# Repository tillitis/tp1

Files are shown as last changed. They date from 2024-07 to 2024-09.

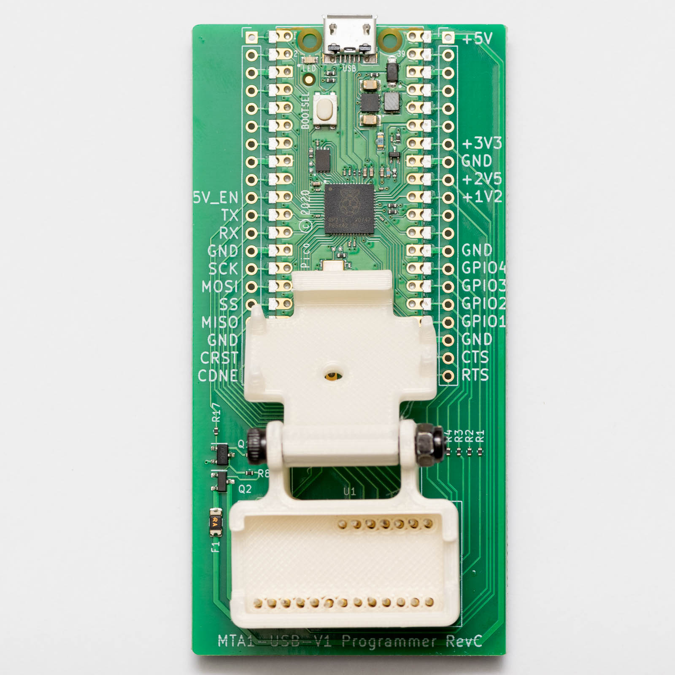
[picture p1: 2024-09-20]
prototypes/mta1-usb-v1-programmer/mta1-usb-v1-programmer.jpg

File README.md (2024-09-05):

# TKey Programmer 1

The TKey Programmer 1 (TP1) board is a tool used to program the FPGA
on a TKey. It consists of a RPI Pico and a jig where the TKey can be
placed.

## General usage

The board is interfaced using USB, and it will display itself as ID
`1209:8886 Generic TP-1`. The TKey is supposed to be placed in the jig
and one closes the lid carefully by pressing in the middle of the jig
(by the hole). To open the lid of the jig, it is easiest to simply
lift up on the lever.

The TP1 board supports two host computer tools to accommodate
programming of the TKey, either `iceprog` or `pynvcm`. See the chapter
in the [TKey Developer Handbook](https://dev.tillitis.se/tp1/) for a
more elaborate description on how to use it.

## Linux device permissions

To allow sudo-less programming, you need to be able to access the TKey
Programmer USB device. This is a raw USB device that is probably not
taken care of by your distribution.

You can install an udev rule that will assign the TP1 to the dialout
group. You will also need to add your user to the dialout group.

Create the following udev rule at `/etc/udev/rules.d`:

```
# TP-1 programmer
SUBSYSTEM=="usb", ENV{DEVTYPE}=="usb_device", ATTR{idVendor}=="1209", ATTR{idProduct}=="8886", MODE="0666", GROUP="dialout"
```

To reload the rules run:

```
sudo udevadm control --reload-rules
sudo usermod -aG dialout ${USER}
```

To apply the new group, log out and then log back in, or run the
command `newgrp dialout` in the terminal that you are working in.

You can check the device permissions to determine if the group was
successfully applied. First, use `lsusb` to find the location of the
programmer:

```
lsusb -d 1209:8886
Bus 001 Device 023: ID 1209:8886 Generic TP-1
```

Then, you can check the permissions by using the bus and device
numbers reported above like this:

```
ls -l /dev/bus/usb/001/023
crw-rw---- 1 root dialout 189, 22 Feb 16 14:58 /dev/bus/usb/001/023
```

Note that this pair of numbers is ephemeral and may change after every
device insertion.

## Firmware
The TP1 board runs a custom firmware developed by Blinkinlabs for
Tillitis. There is also a pre-built firmware binary at
`fw/bin/main.uf2`.

To update the firmware, either build the file `main.uf2` (more
instructions below) or get the pre-built file to your host computer.
Then do the following:

1. Disconnect the programming board from the host computer
2. Press and hold the "BOOTSEL" button on the RPi2040 sub-board on the
programming board
3. Reconnect the programming board to the host computer
4. Release the "BOOTSEL" button after connecting the programming board
to the host. The board should now appear to the host as a USB
connected storage device
5. Open the storage device and drop the firmware file `main.uf2` into
the storage device

The programmer will update its firmware with the file and restart
itself. After rebooting, the storage device will automatically be
disconnected.

### Building the firmware

The firmware requires the Raspberry Pi Pico SDK, the build script
assumes this is located either in your home home directory, or in
`/usr/local`. To clone to the home directory use

```
cd ~
git clone --branch 1.5.1 https://github.com/raspberrypi/pico-sdk.git
cd pico-sdk
git submodule update --init
```

then run the build script in the `fw` folder

```
./build.sh
```

Note that our container image (tkey-builder) places the pico-sdk
directory in `/usr/local`. For normal development, it is usually left
in the user's home directory.

See
[fw/README.md](https://github.com/tillitis/tp1/blob/main/fw//README.md)
for further instructions.

## KiCad

The PCB is built using KiCad version 7. Production files are built in
CI using KiBot, see the Makefile for exact version.

## License
### Hardware
Unless otherwise noted, this project is licensed under CERN Open
Hardware License Version 2 - Strongly Reciprocal, see full license
under [LICENSE.txt](/LICENSE.txt).
```
Copyright Tillitis AB 2022-2024.

This source describes Open Hardware and is licensed under the CERN-OHL-S v2.

You may redistribute and modify this source and make products using it under
the terms of the CERN-OHL-S v2 (https://ohwr.org/cern_ohl_s_v2.txt).

This source is distributed WITHOUT ANY EXPRESS OR IMPLIED WARRANTY,
INCLUDING OF MERCHANTABILITY, SATISFACTORY QUALITY AND FITNESS FOR A
PARTICULAR PURPOSE. Please see the CERN-OHL-S v2 for applicable conditions.

Source location: https://github.com/tillitis/tp1

As per CERN-OHL-S v2 section 4, should You produce hardware based on this
source, You must where practicable maintain the Source Location visible
on the external case of the product or its packaging, and in its
documentation, even after modification.
```

The [CERN-OHL-S user guide](/User-guide-CERN-OHL-S.txt) is included to
make it easier to follow the license, both as a Licensor or a Licensee.

### Firmware
The firmware running on the TP1 is licensed under MIT License, see the
full license [fw/LICENSE](fw/LICENSE).

Copyright (c) 2023 Tillitis AB.

### Raspberry Pi Pico
TKey Programmer board uses the Raspberry Pi Pico hardware, which are
provided by Raspberry Pi Ltd. For more details, visit the official
Raspberry Pi Pico documentation at
https://www.raspberrypi.com/licensing/

## Prototypes

Under `prototypes/`, an earlier version of the TP1 can be found, such as
the `mta1-usb-v1-programmer`.

## History
This repo was created by filtering out relevant commits and files from
the [tillitis/tillits-key1](https://github.com/tillitis/tillitis-key1)
repo.

The filtering removed all files and commits that weren't related to
the tp1 hardware. This was done using
[git-filter-repo](https://github.com/newren/git-filter-repo).

To replicate the results up until commit `f1158b1` in this repo,
checkout commit `354aecb` in `tillitis/tillitis-key1` and run
`git-filter-repo --path hw/boards/tp1 --path
hw/boards/mta1-usb-v1-programmer --path hw/boards/KiCad-RP Pico`

All filtered commits have intact date, author, and code. Some
unrelated files are removed from some commits, but the commit messages
are left unchanged. Commit sha, tags and signatures are new. For
complete history, please see tillitis/tillitis-key1 from commit
`354aecb` and earlier.

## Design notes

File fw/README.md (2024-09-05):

# Ice40 programmer

This firmware allows a Raspberry Pi Pico (or any RP2040) to work as a
programmer for the lattice ice40 parts.

It has been integrated into icestorm:
https://github.com/tillitis/icestorm/tree/interfaces

## Building the firmware

First, follow the details in the toolchain setup document to install
the Raspberry Pi Pico SDK. Then, the firmware can be built by running
the build script:

```
./build.sh
```

Once complete, the output binary is located in build/main.uf2

## Usage

First, program your RPi Pico using the included binary 'main.u2f'. To
do so, disconnect the pico from your computer, press down the
bootloader button, then plug the pico back in. The computer should
detect it as a memory device. Copy the main.u2f file into the root
directory of this memory device. This will program the Pico. Once
completed, the pico should restart and present itself as a USB RAW
device.

To use it with icestorm, the 'iceprog' utility will need to be built
from the above fork. Known issues:

* This version of iceprog is hard-coded to use the pico as a programmer; it
should have a command-line switch to choose the correct programmer
* SRAM programming mode (-S) is untested

TODO: Suggested wiring diagram

TODO: Permissions

## Version checking

The firmware version can be determined from the bcdDevice field in the
USB device descriptor. Known versions are:

| bcdDevice | Version | Description |
| --- | --- | --- |
| 0x0100 | 1.0 | Raw USB test version |
| 0x0200 | 2.0 | Release version |

The command set described in this document describes the version 2.0
format.

## Command set

Commands are sent to the device as [control
transfers](https://www-user.tu-chemnitz.de/~heha/hsn/chm/usb.chm/usb4.htm#Control).
The bRequest field is used to select the commmand, and any
configuration data associated with the command 

| Command | Direction | bRequest | wValue | wIndex | wLength |
| --- | ---  | --- | --- | --- | --- |
| Set pin directions | OUT | 0x30  | 0 | 0 | 8 |
| Set pullups/pulldowns | OUT | 0x31  | 0 | 0 | 12 |
| Set pin values | OUT | 0x32 | 0 | 0 | 8 |
| Get pin values | IN  | 0x32 | 0 | 0 | 4 |
| Configure SPI pins and clock speed | OUT | 0x40 | 0 | 0 | 5 |
| Perform a SPI transfer | OUT | 0x41 | 0 | 0 | 5+n |
| Read data from previous SPI transfer | IN  | 0x41 | 0 | 0 | n |
| Send SPI clocks | OUT | 0x42 | 0 | 0 | 0 |
| Read ADC inputs | IN  | 0x50 | 0 | 0 | 12 |
| Enter bootloader mode  | OUT | 0xE0 | 0 | 0 | 0 |

Additionally, the device supports an additional control transfer to
support driver assignment on Windows:

| Command | Direction | bRequest | wValue | wIndex | wLength | Description |
| ---  | ---  | --- |--- | --- |--- |--- |
| MS_DESCRIPTOR | IN | 0xF8 | 0 | 0 | x | Get a Microsoft OS compatible descriptor |

### Set pin directions

This command is used to set pin directions. The first field is a mask
of pins to update, and the second is a bitmap of the resulting states.
Any pin that has a bit set in the mask will be updated.

Data packet format:

| Offset | Length | Description |
| --- | --- | --- |
| 0x00 | 4 | uint32: Pin mask (1=set direction) |
| 0x04 | 4 | uint32: Pin direction (1=output, 0=input) |

### Set pin pullup/pulldown resistors

This command is used to set pin pullup/pulldown resistors. The first
field is a mask of pins to update, the second is the pull-up states,
and the third is the pull-down states. Any pin that has a bit set in
the mask will be updated.

Data packet format:

| Offset | Length | Description |
| --- | --- | --- |
| 0x00 | 4 | uint32: Pin mask (1=set direction) |
| 0x04 | 4 | uint32: Pin pullups (1=enable, 0=disable) |
| 0x08 | 4 | uint32: Pin pulldowns (1=enable, 0=disable) |

### Set pin values

This command is used to set the value of output pins. The first field
is a mask of pins to update, and the second is a bitmap of new output
values to apply. Any pin that has a bit set in the mask will be
updated.

Data packet format:

| Offset | Length | Description |
| --- | --- | --- |
| 0x00 | 4 | uint32: Pin mask (1=set direction) |
| 0x04 | 4 | uint32: Pin value (1=high, 0=low) |

### Read pin values

This command is used to read the value of all pins. Note that pins
which are confgured as outputs will report their current output
setting.

Data packet format:

| Offset | Length | Description |
| --- | --- | --- |
| 0x05 | 4 | uint32: Pin values (1=high, 0=low) |

### Set SPI configuration

This command is used to configure the SPI engine.

Data packet format:

| Offset | Length | Description |
| --- | --- | --- |
| 0x00 | 1 | GPIO pin number for SCK |
| 0x01 | 1 | GPIO pin number for CS |
| 0x02 | 1 | GPIO pin number for MOSI |
| 0x03 | 1 | GPIO pin number for MISO |
| 0x04 | 1 | SPI clock frequency, in MHz |

### Transfer SPI data

This command is used to send data over the pins currently configured
as the SPI interface. This command performs a full-duplex read/write
operation, and stores the read data in a buffer. To retrieve the data
read during this operation, issue a read command.

Data packet format:

| Offset | Length | Description |
| --- | --- | --- |
| 0x00 | 1 | 0: don't toggle CS; any other value: toggle CS |
| 0x01 | 4 | Bytes to transfer |
| 0x05 | 1-2040 | SPI data to transfer |

### Get data read during previous SPI transaction

This command is used to retrieve any data transferred during the
previous SPI transaction.

Data packet format:

| Offset | Length | Description |
| --- | --- | --- |
| 0x00 | 1-2040 | SPI data to transfer |

### SPI clock out

This command is used to toggle the SPI clock pin, but doesn't transfer
any data.

Data packet format:

| Offset | Length | Description |
| --- | --- | --- |
| 0x00 | 4 | Number of SPI bytes to clock |

### Read ADCs

This command is used to read the analog value of analog input pins
0-2. Each value is returned as a uint32_t value representing the
reading in microvolts.

Data packet format:

| Offset | Length | Description |
| --- | --- | --- |
| 0x01 | 4 | ADC channel 0 value, in microvolts |
| 0x05 | 4 | ADC channel 1 value, in microvolts |
| 0x09 | 4 | ADC channel 2 value, in microvolts |

### Bootloader

This command is used to put the device in bootloader mode. No data is
sent during this

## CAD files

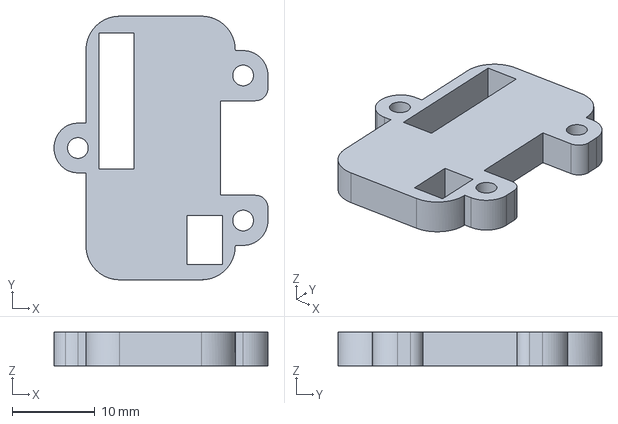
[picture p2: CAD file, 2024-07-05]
hw/clip_plastic/clip_base_spacer_30.stp
25.8 x 31.8 x 4.10 mm

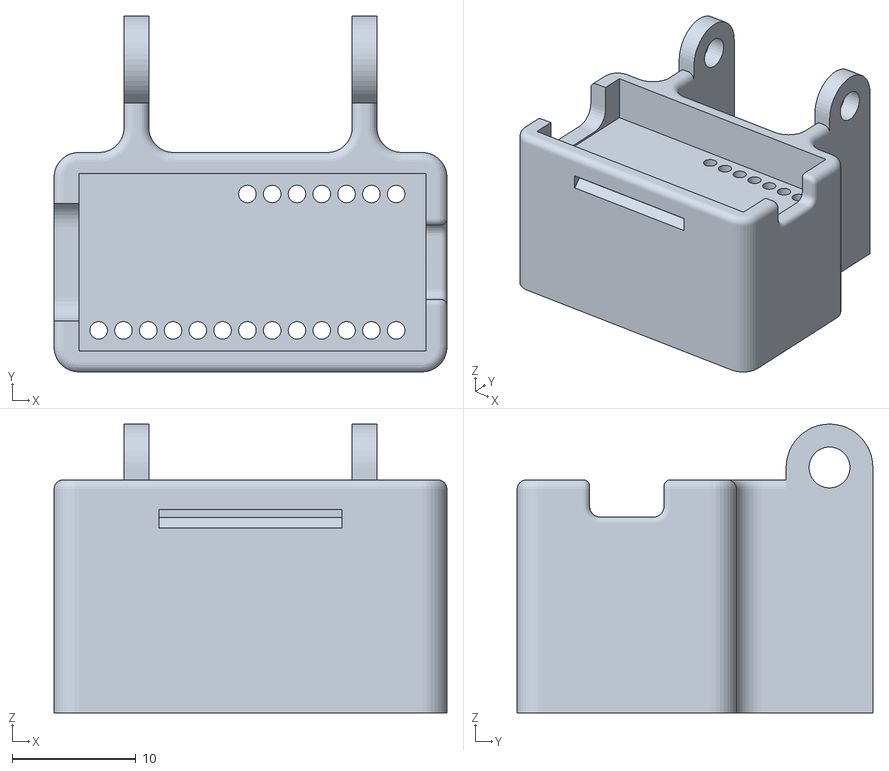
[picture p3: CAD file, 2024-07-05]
prototypes/mta1-usb-v1-programmer/clip_plastic/base-tk1.stl
31.7 x 28.7 x 23.3

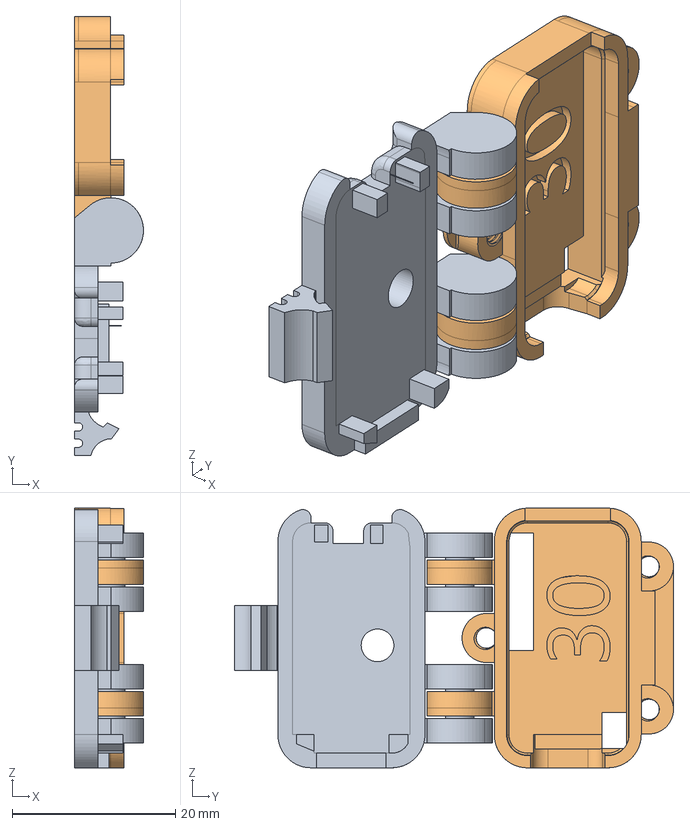
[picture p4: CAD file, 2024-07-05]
hw/clip_plastic/clip_base_30.stp
8.45 x 53.8 x 31.8 mm

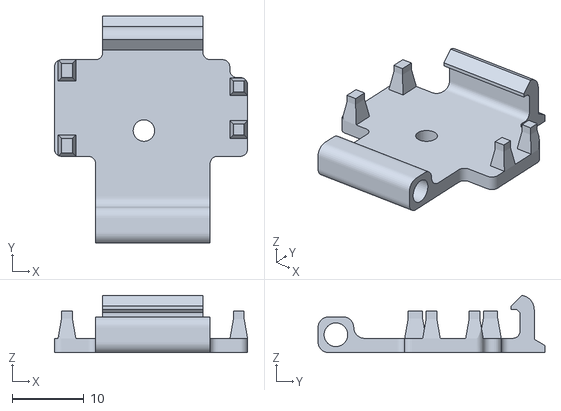
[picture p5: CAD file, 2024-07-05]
prototypes/mta1-usb-v1-programmer/clip_plastic/clip-tk1.stl
27.0 x 31.7 x 8.00

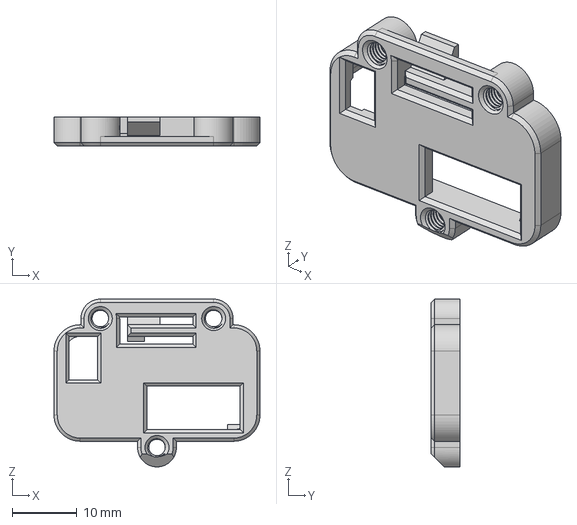
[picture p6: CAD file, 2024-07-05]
hw/clip_plastic/clip_base_15.step
31.8 x 4.40 x 25.9 mm

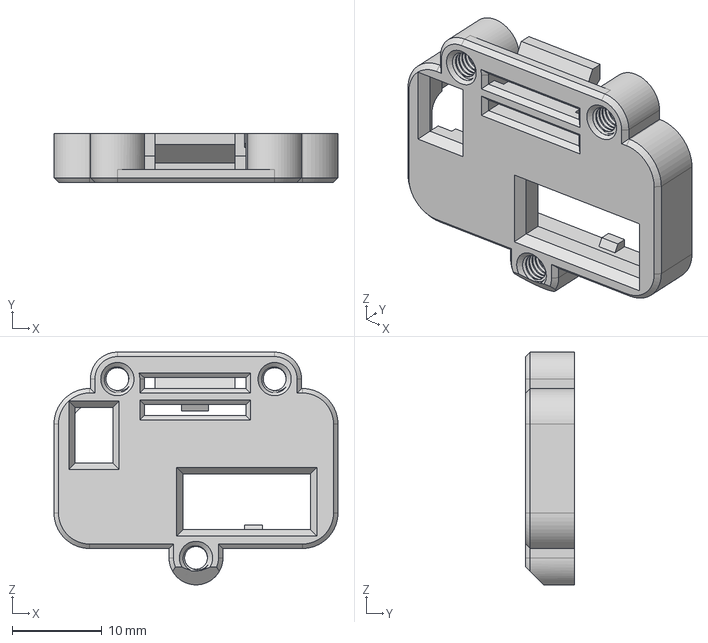
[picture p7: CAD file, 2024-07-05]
hw/clip_plastic/clip_base_24.step
31.6 x 5.40 x 25.9 mm

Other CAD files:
prototypes/mta1-usb-v1-programmer/clip_plastic/base-mta1.stl
prototypes/mta1-usb-v1-programmer/clip_plastic/clip-mta1.stl
hw/clip_plastic/clip_base_15.f3d
hw/clip_plastic/clip_base_24.f3d
hw/clip_plastic/clip_base_30.3mf

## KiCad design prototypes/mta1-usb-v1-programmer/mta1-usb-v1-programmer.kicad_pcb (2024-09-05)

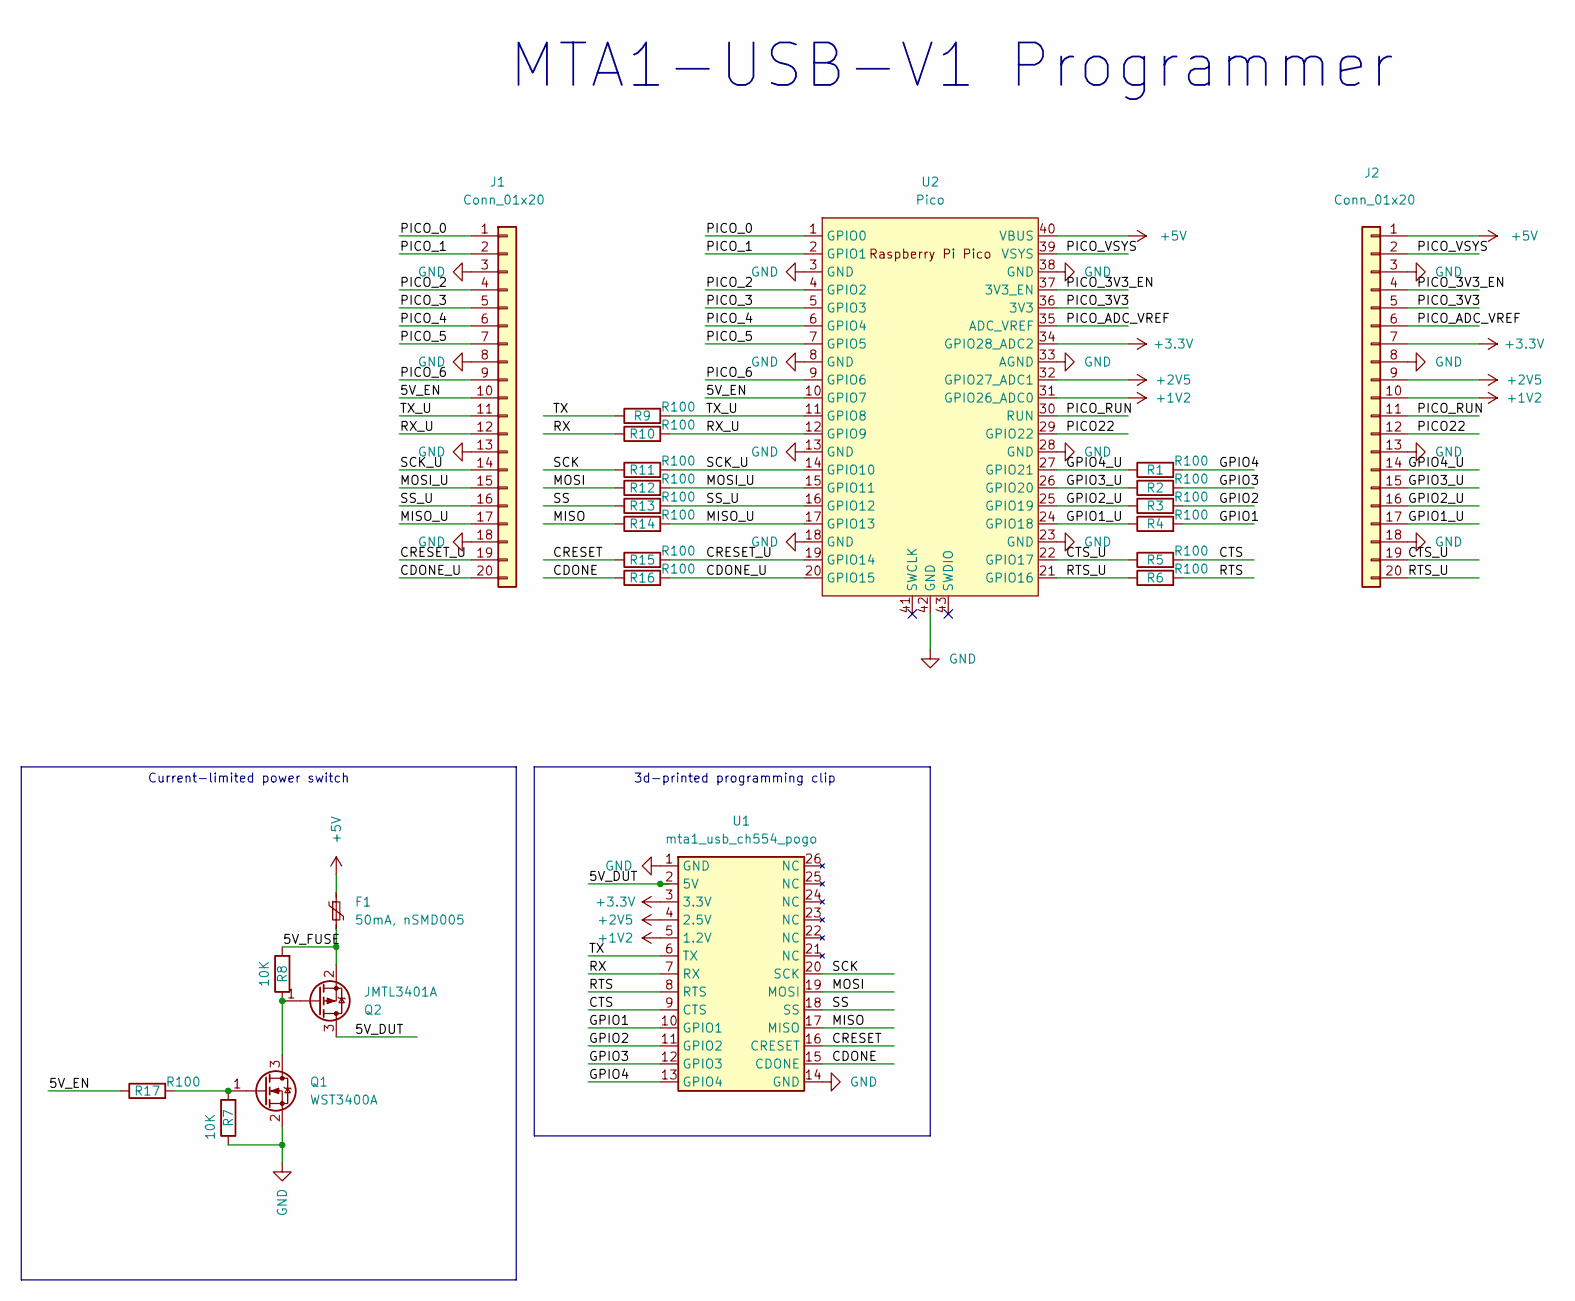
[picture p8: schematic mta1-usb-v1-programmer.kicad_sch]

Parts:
F1: 50mA, nSMD005; Fuse_1206_3216Metric; Manufacturer Part Number SMD1206P005TF
J1, J2: Conn_01x20; PinHeader_1x20_P2.54mm_Vertical
Q1: WST3400A; SOT-23; Manufacturer Part Number WST3400A
Q2: JMTL3401A; SOT-23; Manufacturer Part Number JMTL3401A
R1, R2, R3, R4, R5, R6, R9, R10, R11, R12, R13, R14, R15, R16, R17: R100; ERJ2G(0402)_L; Manufacturer Part Number AF0402FR-07100RL
R7, R8: 10K; ERJ2G(0402)_L; Manufacturer Part Number AT0402FRE0710KL
U1: mta1_usb_ch554_pogo
U2: Pico; RPi_Pico_SMD_TH; Manufacturer Part Number SC0915

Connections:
+1V2: J2.10, U1.5 (1.2V), U2.31 (GPIO26_ADC0)
+2V5: J2.9, U1.4 (2.5V), U2.32 (GPIO27_ADC1)
+3V3: J2.7, U1.3 (3.3V), U2.34 (GPIO28_ADC2)
+5V: F1.1, J2.1, U2.40 (VBUS)
/5V_DUT: Q2.3 (D), U1.2 (5V)
/5V_EN: J1.10, R17.1, U2.10 (GPIO7)
/5V_FUSE: F1.2, Q2.2 (S), R8.2
/CDONE: R16.1, U1.15 (CDONE)
/CDONE_U: J1.20, R16.2, U2.20 (GPIO15)
/CRESET: R15.1, U1.16 (CRESET)
/CRESET_U: J1.19, R15.2, U2.19 (GPIO14)
/CTS: R5.2, U1.9 (CTS)
/CTS_U: J2.19, R5.1, U2.22 (GPIO17)
/GPIO1: R4.2, U1.10 (GPIO1)
/GPIO1_U: J2.17, R4.1, U2.24 (GPIO18)
/GPIO2: R3.2, U1.11 (GPIO2)
/GPIO2_U: J2.16, R3.1, U2.25 (GPIO19)
/GPIO3: R2.2, U1.12 (GPIO3)
/GPIO3_U: J2.15, R2.1, U2.26 (GPIO20)
/GPIO4: R1.2, U1.13 (GPIO4)
/GPIO4_U: J2.14, R1.1, U2.27 (GPIO21)
/MISO: R14.1, U1.17 (MISO)
/MISO_U: J1.17, R14.2, U2.17 (GPIO13)
/MOSI: R12.1, U1.19 (MOSI)
/MOSI_U: J1.15, R12.2, U2.15 (GPIO11)
/PICO22: J2.12, U2.29 (GPIO22)
/PICO_0: J1.1, U2.1 (GPIO0)
/PICO_1: J1.2, U2.2 (GPIO1)
/PICO_2: J1.4, U2.4 (GPIO2)
/PICO_3: J1.5, U2.5 (GPIO3)
/PICO_3V3: J2.5, U2.36 (3V3)
/PICO_3V3_EN: J2.4, U2.37 (3V3_EN)
/PICO_4: J1.6, U2.6 (GPIO4)
/PICO_5: J1.7, U2.7 (GPIO5)
/PICO_6: J1.9, U2.9 (GPIO6)
/PICO_ADC_VREF: J2.6, U2.35 (ADC_VREF)
/PICO_RUN: J2.11, U2.30 (RUN)
/PICO_VSYS: J2.2, U2.39 (VSYS)
/RTS: R6.2, U1.8 (RTS)
/RTS_U: J2.20, R6.1, U2.21 (GPIO16)
/RX: R10.1, U1.7 (RX)
/RX_U: J1.12, R10.2, U2.12 (GPIO9)
/SCK: R11.1, U1.20 (SCK)
/SCK_U: J1.14, R11.2, U2.14 (GPIO10)
/SS: R13.1, U1.18 (SS)
/SS_U: J1.16, R13.2, U2.16 (GPIO12)
/TX: R9.1, U1.6 (TX)
/TX_U: J1.11, R9.2, U2.11 (GPIO8)
GND: J1.3, J1.8, J1.13, J1.18, J2.3, J2.8, J2.13, J2.18, Q1.2 (S), R7.1, U1.1 (GND), U1.14 (GND), U2.3 (GND), U2.8 (GND), U2.13 (GND), U2.18 (GND), U2.23 (GND), U2.28 (GND), U2.33 (AGND), U2.38 (GND), U2.42 (GND)
unnamed: Q1.1 (G), R7.2, R17.2
unnamed: Q1.3 (D), Q2.1 (G), R8.1

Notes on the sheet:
Current-limited power switch
MTA1-USB-V1 Programmer
3d-printed programming clip

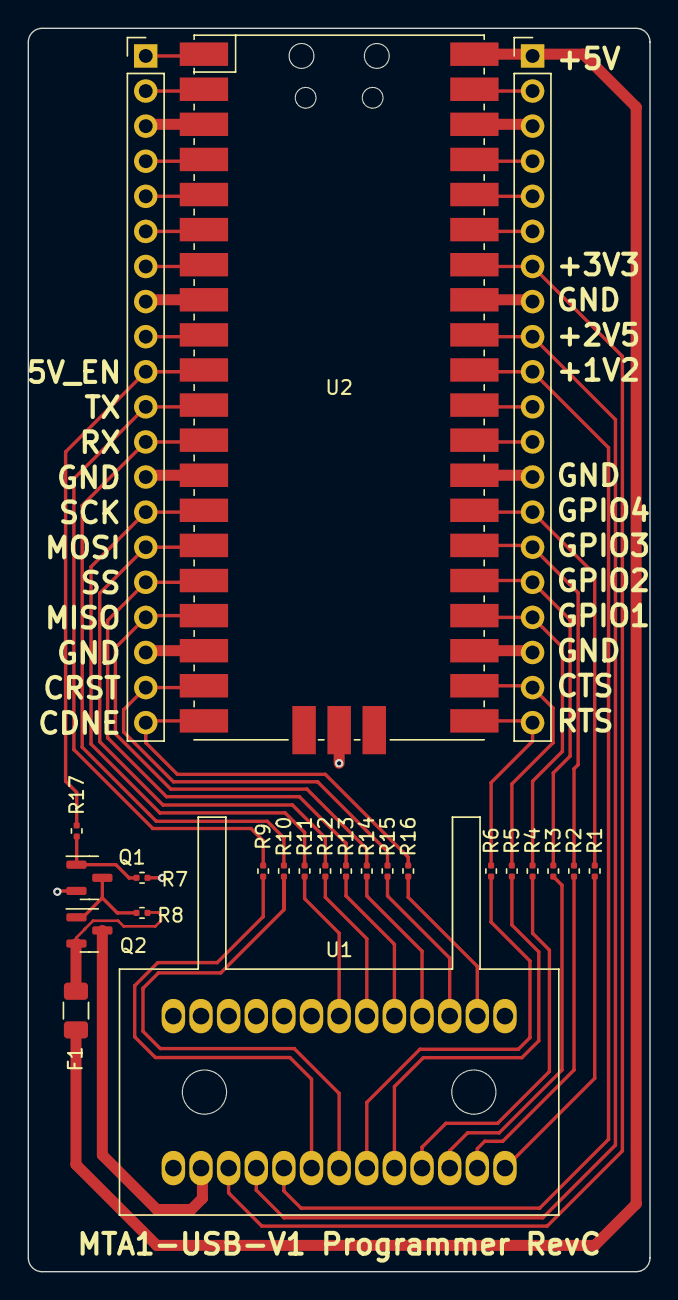
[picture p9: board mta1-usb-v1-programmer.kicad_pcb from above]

Board: 2 copper layers, 45.0 x 90.0 mm, 24 parts (0 on the bottom side), 51 nets.

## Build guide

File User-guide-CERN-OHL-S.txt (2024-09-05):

CERN Open Hardware Licence Version 2 - Strongly Reciprocal

                           User Guide

                         September 2, 2020
                         Guide version: 1.0

1 Introduction

This document contains guidelines on how to apply the CERN-OHL-S v2 to a given
hardware design, and on the use of hardware designs licensed under CERN-OHL-S
v2. This means we will be talking to you sometimes as a licensor, and other
times as a licensee.
As a licensor, there are many ways in which you can make it clear to your
licensees that you are sharing your designs under the licence. These guidelines
are only to be taken as advice, illustrating some ways in which we think this
can be done efficiently.
To help you distinguish between requirements imposed by the licence (mostly as a
licensee) and our suggestions to you (mostly as a licensor), we will use the
word 'rule' for the former and the word 'suggestion' for the latter. Any
perceived contradiction between these guidelines and the licence text should of
course be resolved in favour of the licence text.

2 How to apply CERN-OHL-S v2 to a hardware design

2.1 Pre-requisite

Authorship/ownership of the design must be clear and undisputed. Only the legal
owner of the rights in the hardware design may decide under what conditions to
make it available. Generally, if ownership is vested in more than one
person/entity, there must be an agreement among the owners (or a chain of
compatible licences from each of them) to release the hardware design as open
hardware, and under the CERN-OHL-S v2 in particular.

2.2 Your sources

Nowadays, most designers who intend to share their work do so by hosting their
design files (sources) in a publicly-accessible repository using version control
systems such as git. The sites hosting these repositories usually provide users
with the convenience of downloading a whole repository as a compressed (e.g.
zip) file. Using these platforms is a very effective way of working: it makes it
easier for you to receive feedback, shows your users the complete history of the
project and allows them to easily start using it and contributing improvements.

2.2.1 Suggestion: try to host your design in a publicly-accessible repository
      using version control. If that is not possible, compress your whole
      directory structure into one file and publish that file, so users get your
      whole project in one go.

If your goal is to share, it makes sense to provide enough information to users
about the contents of the design package they download, and to make it easy for
them to browse that information. For example, if you have designed your hardware
using proprietary tools, people who download the design files may not have
access to the tools you used. Sometimes you can also provide exported versions
of those files which, although not as useful for modification as the originals,
will make life easier for people who want to understand your designs. For
example, PCB schematics and layout can be exported as pdf files, and 3D
mechanical designs can be exported to the STEP format.

2.2.2 Suggestion: include in your design sources versions of the files exported
      to formats everybody can read. It would be helpful to specify the tools
      you used, and, if they are publicly available under free and open source
      licences, provide information about where the recipient can find them.

It can also be good to let people know that you are following this guide, so
they see why you are doing things in this or that way.

2.2.3 Suggestion: include a copy of this user guide, in pdf or plain text
      format, in your sources.

Of course, although not strictly necessary, you should also include a copy of
the licence text (CERN-OHL-S v2 in this case) in pdf or plain text form. Your
design files will anyway be identified as licensed under that licence, with a
URL pointing to the licence text, but it does not hurt to include the licence
text in the source package for the convenience of the user and to make it very
visible that the whole design is open source.

2.2.4 Suggestion: include a copy of the CERN-OHL-S v2 licence text, in pdf or
      plain text format, in your sources, and failing that, provide a link to
      the licence at https://ohwr.org/cern_ohl_s_v2.txt.

One of the requirements for licensees who make modifications to the design and
publish those modifications is to make them explicit in a dedicated text file.
As a licensor, you can make this obligation more easy for licensees to see and
bear in mind by including a placeholder file called CHANGES.txt in your sources.

2.2.5 Suggestion: include an empty CHANGES.txt file in your sources. You may
      write a few lines in the beginning of the file stating that anyone
      modifying the design should provide brief information about the
      modifications, including the date they were made, and stating that
      information about the design should be added but never removed from that
      file. It could also state that, according to section 3.3.b of the licence,
      licensees should provide a brief entry with a date and the nature of the
      modification for each design change. For example '26 April 2020: AC/DC
      power converter circuit removed as AC input no longer necessary'.

Now, as you have seen, as the initial licensor, relatively few rules apply to
you. We are going to assume that it is your intent to license your design under
CERN-OHL-S v2 though, and in that sense the minimal requirements are going to be
described as 'rules' below. Some files can easily include a header or a text box
with copyright and licensing information which will be easily visible to whoever
opens them. For file types which do not easily grant that possibility, consider
using a separate text file taking as its name the name of the original file with
'.license' appended to it. So if you have e.g. a file called
`my_3d_design.FCStd', you can add another file in the same directory called
`my_3d_design.FCStd.license' which is a text file containing copyright and
licensing information. If the number of files in your project is large and the
'.license' method is deemed too cumbersome, you can centralise all your
licensing information in a single text file following the Debian DEP5
specification. Both the '.license' and the DEP5 methods are suggested in the
REUSE guidelines. See https://reuse.software/for details.

2.2.6 Rule: include for each source file, either embedded in the file itself or
      in a separate text file which refers to it:
       (a) a copyright notice reflecting actual ownership;
       (b) a notice that the hardware design source is licensed under the CERN-
           OHL-S v2, possibly with a link to https://ohwr.org/cern_ohl_s_v2.txt:
             i."Licensed under CERN-OHL-S v2 or any later version" or
            ii."Licensed under CERN-OHL-S v2";
       (c) a disclaimer of warranties;
       (d) a Source Location if you wish to specify one;
       (e) optionally, a Notice specifying that you wish the Source Location to
           remain visible on the Product (or its packaging, or in its
           documentation) even after modifications.

Here is an example for a hypothetical designer called Sam Smith hosting a
design called Gizmo at https://example_url:

 ------------------------------------------------------------------------------
| Copyright Sam Smith 2020.                                                    |
|                                                                              |
| This source describes Open Hardware and is licensed under the CERN-OHL-S v2. |
|                                                                              |
| You may redistribute and modify this source and make products using it under |
| the terms of the CERN-OHL-S v2 (https://ohwr.org/cern_ohl_s_v2.txt).         |
|                                                                              |
| This source is distributed WITHOUT ANY EXPRESS OR IMPLIED WARRANTY,          |
| INCLUDING OF MERCHANTABILITY, SATISFACTORY QUALITY AND FITNESS FOR A         |
| PARTICULAR PURPOSE. Please see the CERN-OHL-S v2 for applicable conditions.  |
|                                                                              |
| Source location: https://example_url                                         |
|                                                                              |
| As per CERN-OHL-S v2 section 4, should You produce hardware based on this    |
| source, You must where practicable maintain the Source Location visible      |
| on the external case of the Gizmo or other products you make using this      |
| source.                                                                      |
 ------------------------------------------------------------------------------

The first three lines in the example above, containing copyright and licence
type, can be substituted by a valid SPDX header, like this:

SPDX-FileCopyrightText: 2020 Sam Smith <sam@example.com>
SPDX-License-Identifier: CERN-OHL-S-2.0

or, in case the 'or any later version' option is preferred:

SPDX-FileCopyrightText: 2020 Sam Smith <sam@example.com>
SPDX-License-Identifier: CERN-OHL-S-2.0+

2.2.7 Suggestion: use standard SPDX headers whenever possible so that your
      choice of licence is easy to understand by humans and computers alike.

Why would you license your design under 'CERN-OHL-S v2 or any later version'?
Imagine we discovered a shortcoming of the licence which made us write a new
version, let's say version 3.0, to fix it. Let us further imagine that we
decided to make v3 incompatible with v2 (this actually happened with the GPL).
If you licensed your design under 'v2 only' that means it could not be combined
with new designs licensed under v3. If, on the other hand, you license your
design under 'v2 or any later version', you give future licensees the option of
interpreting the design as licensed under the hypothetical v3, and there would
be no compatibility issues. This is quite an important decision to take when you
use a reciprocal licence, so we thought we'd mention it in this guide. You have
to make your own judgment as to whether you believe that CERN can be trusted to
ensure that future versions of the CERN-OHL will be similar in spirit and effect
to this version.

2.2.8 Suggestion: give some thought to the 'or any later version' option before
      publishing your design under CERN-OHL-S v2.

We are going to assume that you, as a licensor, want people who receive a
product based on your design to know that it is Open Hardware and where they can
find the design files for that product, hence:

2.2.9 Rule: include in a part of the Source corresponding to a visible part of
      the Product (e.g. silkscreen or top copper for a printed circuit board):
        (a) the licence notice: "Licensed under CERN-OHL-S v2";
        (b) the Source Location.

2.2.10 Suggestion: You can optionally include a copyright notice to be printed
       on the Product (remember you must keep intact any Notices in the source,
       though). If you do, and your design includes part of other designs, you
       should at least acknowledge the work is not all your own by using e.g.
       Copyright Sam Smith and others. In any case, do not include the CERN
       logo.

2.3 A Note on Components

If your design is modular, consider licensing each of the components you have
designed separately, and then having an overarching design, also licensed under
an appropriate variant of CERN-OHL which contains each of the sub-components as
an Available Component. This will make life easier for licensees who only want
to make use of one component of your design.

3 How to deal with hardware designs licensed under CERN-OHL-S v2

Generally speaking, you must comply with the requirements applying to a
particular design detailed in the accompanying licence. If you receive hardware
designs licensed under the CERN-OHL-S v2, the requirements are to:

3.1 Rule: keep intact all the copyright, acknowledgement and trademark notices
    and Source Location notices that are on the hardware design sources.

3.2 Rule: keep intact the references to the CERN-OHL-S v2.

3.3 Rule: keep intact the disclaimer of warranties.

3.1 Design modifications and publication

If you modify a hardware design licensed by someone else under CERN-OHL-S v2,
and you want to publish your modified design, or you need to publish it e.g. as
a result of the obligations attached to the production and distribution of
products, you must:

3.1.1 Rule: keep intact all the notices referred to above, although you may
      remove notices that are no longer relevant to your design (for example, if
      the design you are using contains a power supply and a processor board,
      and you are only using the processor board in your own design, you can
      remove the notices relating to the power supply, so long as you are sure
      they only relate to the power supply).

3.1.2 Rule: include notices stating that you have modified the hardware de-
      signs, giving a date and information about the modifications you have made
      (e.g. in a CHANGES.txt file).

3.1.3 Rule: add the appropriate copyright notice and Source Location to the
      modifications that were made.

3.1.4 Rule: license the modifications under the 'CERN-OHL-S v2' (or 'CERN- OHL-S
      v2 or any later version' if permitted by the original licensor, and all
      other components of the design allow you to license with the 'or any later
      version' option).

3.1.5 Rule: if your design is a modification of someone else's design, or
      incorporates parts of another's design, and in each case the other's
      design is released under CERN-OHL, CERN-OHL-W or CERN-OHL-S you must (if
      your tools allow this) include in your design sources versions of the
      files exported to formats everybody can read using tools available under a
      free or open source software licence. By CERN-OHL we mean any of the
      earlier versions of the licence, prior to v2.

3.2 Hardware production and distribution

If, as a licensee, you want to produce hardware based on a design licensed under
CERN-OHL-S v2 and/or distribute that hardware, you need to:

3.2.1 Rule: either provide each recipient with a copy of the Complete Source or
      ensure that each recipient is notified of the Source Location of the
      Complete Source.

By Complete Source, we mean all files needed to make the hardware. Please see
the licence text for details. You also need to respect, if applicable, the
will expressed by the licensor to have a clear visual indication of the Source
Location on the hardware:

3.2.2 Rule: if specified in a Notice by the licensor, the Product must visibly
      and securely display the Source Location on it or its packaging or
      documentation in the manner specified in that Notice.

4 Asking for help

If there is something unclear in this guide, or you have any question on how to
apply the licence, the best place to ask is the CERN OHL forum at
https://forums.ohwr.org/c/cernohl. You may also find useful information in the
FAQs at https://www.ohwr.org/project/cernohl/wikis/faq.

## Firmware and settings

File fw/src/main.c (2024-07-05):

/*
 * The MIT License (MIT)
 *
 * Copyright (c) 2019 Ha Thach (tinyusb.org)
 *
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
 */

#include <stdlib.h>
#include <stdio.h>
#include <string.h>
#include <hardware/gpio.h>
#include <hardware/adc.h>
#include "pico/bootrom.h"
#include "bsp/board.h"
#include "tusb.h"
#include "pio_spi.h"

//--------------------------------------------------------------------+
// MACRO CONSTANT TYPEDEF PROTYPES
//--------------------------------------------------------------------+

/* Blink pattern
 * - 250 ms  : device not mounted
 * - 1000 ms : device mounted
 * - 2500 ms : device is suspended
 */
enum
{
    BLINK_NOT_MOUNTED = 250,
    BLINK_MOUNTED = 1000,
    BLINK_SUSPENDED = 2500,
};


static bool do_reset = false;

static uint32_t blink_interval_ms = BLINK_NOT_MOUNTED;

#define BULK_TRANSFER_MAX_SIZE 2048 // Maximum control transfer data length
#define SPI_MAX_TRANSFER_SIZE (BULK_TRANSFER_MAX_SIZE-8)


pio_spi_inst_t spi = {
    .pio = pio0,
    .sm = 0,
    .cs_pin = 0
};

uint pio_offset;

void led_blinking_task(void);

void pins_init();

/*------------- MAIN -------------*/
int main(void)
{
    board_init();
    tusb_init();

    pio_offset = pio_add_program(spi.pio, &spi_cpha0_program);

    pins_init();

    adc_init();

    while (1)
    {
        tud_task(); // tinyusb device task
        led_blinking_task();

        if(do_reset) {
            reset_usb_boot(0,0);
        }
    }

    return 0;
}

//--------------------------------------------------------------------+
// Device callbacks
//--------------------------------------------------------------------+

// Invoked when device is mounted
void tud_mount_cb(void)
{
    blink_interval_ms = BLINK_MOUNTED;
}

// Invoked when device is unmounted
void tud_umount_cb(void)
{
    blink_interval_ms = BLINK_NOT_MOUNTED;
}

// Invoked when usb bus is suspended
// remote_wakeup_en : if host allow us  to perform remote wakeup
// Within 7ms, device must draw an average of current less than 2.5 mA from bus
void tud_suspend_cb(bool remote_wakeup_en)
{
    (void)remote_wakeup_en;
    blink_interval_ms = BLINK_SUSPENDED;
}

// Invoked when usb bus is resumed
void tud_resume_cb(void)
{
    blink_interval_ms = BLINK_MOUNTED;
}

#define PIN_COUNT 32 // PIN_MASK is 32 bits, so that's the max number of pins available
#define PIN_MASK (0b00011100011111111111111111111111)
// #define PIN_MASK ((1<<PIN_COUNT) - 1)
// #define PIN_MASK (0xFFFFFFFF)

void pins_init()
{
    gpio_init_mask(PIN_MASK);
}

//! @brief Set the pull-up state for the gpios specified in the pinmask
void set_pulls_masked(
    const uint32_t mask,
    const uint32_t ups,
    const uint32_t downs)
{
    for (int gpio = 0; gpio < PIN_COUNT; gpio++)
    {
        if (!(PIN_MASK & (1 << gpio)))
            continue;

        if (mask & (1 << gpio))
        {
            gpio_set_pulls(gpio, ups & (1 << gpio), downs & (1 << gpio));
        }
    }
}

uint32_t get_directions_all() {
    uint32_t pin_directions = 0;

    for (int gpio = 0; gpio < PIN_COUNT; gpio++)
    {
        pin_directions |= (gpio_get_dir(gpio)) << gpio;
    }

    return pin_directions;
}

void spi_xfer(bool handle_cs,
                 const uint32_t byte_count,
                 uint8_t const *buf_out,
                 uint8_t *buf_in)
{
    if(byte_count > SPI_MAX_TRANSFER_SIZE)
        return;

    if((buf_in == NULL) && (buf_out == NULL))
        return;

    if(buf_in != NULL)
        memset(buf_in, 0, SPI_MAX_TRANSFER_SIZE);

    if(handle_cs)
        gpio_put(spi.cs_pin, false);

    if(buf_in == NULL) { // Write transaction
        pio_spi_write8_blocking(&spi, buf_out, byte_count);
    }
    else if(buf_out == NULL) { // Read transaction
        pio_spi_read8_blocking(&spi, buf_in, byte_count);
    }
    else { // Full-duplex transaction
        pio_spi_write8_read8_blocking(&spi, buf_out, buf_in, byte_count);
    }

    if(handle_cs)
        gpio_put(spi.cs_pin, true);
}

uint32_t adc_sample_input(uint8_t input)
{
    if (input > 3)
    {
        return 0;
    }

    // Configure the GPIO
    adc_gpio_init(input + 26);

    adc_select_input(input);

    // 12-bit conversion, assume max value == ADC_VREF == 3.3 V
    const uint32_t conversion_factor = 3300000 / (1 << 12); // microvolts per sample
    uint16_t result = adc_read();

    return result * conversion_factor;
}

uint32_t read_uint32(uint8_t const *buffer)
{
    const uint32_t val =
        (*(buffer + 0) << 24) + (*(buffer + 1) << 16) + (*(buffer + 2) << 8) + (*(buffer + 3) << 0);
    return val;
}

void write_uint32(uint32_t val, uint8_t *buffer)
{
    buffer[0] = ((val >> 24) & 0xFF);
    buffer[1] = ((val >> 16) & 0xFF);
    buffer[2] = ((val >> 8) & 0xFF);
    buffer[3] = ((val >> 0) & 0xFF);
}


typedef enum
{
    COMMAND_PIN_DIRECTION = 0x30,           // Configurure GPIO pin directions
    COMMAND_PULLUPS = 0x31,                 // Configure GPIO pullups
    COMMAND_PIN_VALUES = 0x32,              // Set GPIO output values
    COMMAND_SPI_CONFIGURE = 0x40,           // Configure SPI pins
    COMMAND_SPI_XFER = 0x41,                // SPI transaction with CS pin
    COMMAND_SPI_CLKOUT = 0x42,              // Just toggle the clock
    COMMAND_ADC_READ = 0x50,                // Read ADC inputs
    COMMAND_BOOTLOADER = 0xE0,              // Jump to bootloader mode

    COMMAND_MS_OS_DESCRIPTOR = 0xF8
} command_t;

static const uint8_t microsoft_os_compatible_id_desc[] = {
	40, 0, 0, 0, // total length, 16 header + 24 function * 1
	0, 1, // Version 1
	4, 0, // Extended compatibility ID descriptor index
	1, // Number of function sections
	0, 0, 0, 0, 0, 0, 0, // Reserved
	0, // Interface number
	1, // Reserved
	'W','I','N','U','S','B',0,0, // compatibleID
	0,0,0,0,0,0,0,0,             // subCompatibleID
	0,0,0,0,0,0 // Reserved
};

uint8_t out_buffer[BULK_TRANSFER_MAX_SIZE]; // Host->Device data
uint8_t in_buffer[BULK_TRANSFER_MAX_SIZE];  // Holds Device->Host data

uint8_t spi_in_buffer[SPI_MAX_TRANSFER_SIZE];   // Holds read values from last SPI transfer

// Invoked when a control transfer occurred on an interface of this class
// Driver response accordingly to the request and the transfer stage (setup/data/ack)
// return false to stall control endpoint (e.g unsupported request)
bool tud_vendor_control_xfer_cb(uint8_t rhport, uint8_t stage, tusb_control_request_t const *request)
{
    // Only handle vendor requests
    if (request->bmRequestType_bit.type != TUSB_REQ_TYPE_VENDOR)
        return false;

    if ((stage == CONTROL_STAGE_SETUP) && (request->bmRequestType_bit.direction == 1))
    { // Device to host (IN)
        memset(in_buffer, 0, sizeof(in_buffer));

        switch (request->bRequest)
        {
	    case COMMAND_MS_OS_DESCRIPTOR:
		// TODO: Check index
            memcpy(in_buffer,
			    microsoft_os_compatible_id_desc,
			    sizeof(microsoft_os_compatible_id_desc)
			    );
            return tud_control_xfer(rhport,
			    request,
			    (void *)(uintptr_t)in_buffer,
			    sizeof(microsoft_os_compatible_id_desc)
			    );
            break;

        case COMMAND_PIN_VALUES:
            write_uint32(gpio_get_all() & PIN_MASK, &in_buffer[0]);
            return tud_control_xfer(rhport, request, (void *)(uintptr_t)in_buffer, 4);
            break;

        case COMMAND_ADC_READ:
            write_uint32(adc_sample_input(0), &in_buffer[0]);
            write_uint32(adc_sample_input(1), &in_buffer[4]);
            write_uint32(adc_sample_input(2), &in_buffer[8]);
            return tud_control_xfer(rhport, request, (void *)(uintptr_t)in_buffer, (3*4));
            break;

        case COMMAND_SPI_XFER:
            return tud_control_xfer(rhport, request, (void *)(uintptr_t)spi_in_buffer, sizeof(spi_in_buffer));
            break;

        default:
            break;
        }
    }
    else if ((stage == CONTROL_STAGE_SETUP) && (request->bmRequestType_bit.direction == 0))
    { // Host to device (OUT): Set up request to handle DATA stage
        switch (request->bRequest)
        {
        case COMMAND_PIN_DIRECTION:
        case COMMAND_PULLUPS:
        case COMMAND_PIN_VALUES:
        case COMMAND_SPI_CONFIGURE:
        case COMMAND_SPI_XFER:
        case COMMAND_SPI_CLKOUT:
            return tud_control_xfer(rhport, request, (void *)(uintptr_t)out_buffer, sizeof(out_buffer));
            break;

	case COMMAND_BOOTLOADER:
            do_reset = true;
            return true;
            break;

        default:
            break;
        }
    }
    else if ((stage == CONTROL_STAGE_ACK) && (request->bmRequestType_bit.direction == 0))
    { // Host to device (OUT): Handle data
        switch (request->bRequest)
        {
        case COMMAND_PIN_DIRECTION:
            gpio_set_dir_masked(
                read_uint32(&out_buffer[0]) & PIN_MASK,
                read_uint32(&out_buffer[4]) & PIN_MASK);
            return true;
            break;

        case COMMAND_PULLUPS: // set pullups/pulldowns
            set_pulls_masked(
                read_uint32(&out_buffer[0]) & PIN_MASK,
                read_uint32(&out_buffer[4]) & PIN_MASK,
                read_uint32(&out_buffer[8]) & PIN_MASK);
            return true;
            break;
            
        case COMMAND_PIN_VALUES: // set pin values
            gpio_put_masked(
                read_uint32(&out_buffer[0]) & PIN_MASK,
                read_uint32(&out_buffer[4]) & PIN_MASK);
            return true;
            break;

        case COMMAND_SPI_CONFIGURE:
            if(out_buffer[4] == 0)
                return false;

            pio_spi_init(spi.pio, spi.sm, pio_offset,
                         8,       // 8 bits per SPI frame
                         (31.25f/out_buffer[4]),  // 1 MHz @ 125 clk_sys
                         false,   // CPHA = 0
                         false,   // CPOL = 0
                         out_buffer[0], //sck
                         out_buffer[2], // mosi
                         out_buffer[3]  // miso
            );
            spi.cs_pin = out_buffer[1]; // cs

            return true;
            break;

        case COMMAND_SPI_XFER:
            spi_xfer(
                out_buffer[0],  // CS
                read_uint32(&out_buffer[1]),    // byte length
                &out_buffer[5], // data
                spi_in_buffer
                );
            
            return true;
            break;

        case COMMAND_SPI_CLKOUT:
            spi_xfer(
                false,
                read_uint32(&out_buffer[0]),
                NULL,              
                spi_in_buffer
                );
            
            return true;
            break;



        default:
            break;
        }
    }
    else {
        return true;
    }

    // stall unknown request
    return false;
}

//--------------------------------------------------------------------+
// BLINKING TASK
//--------------------------------------------------------------------+
void led_blinking_task(void)
{
    static uint32_t start_ms = 0;
    static bool led_state = false;

    // Blink every interval ms
    if (board_millis() - start_ms < blink_interval_ms)
        return; // not enough time
    start_ms += blink_interval_ms;

    board_led_write(led_state);
    led_state = 1 - led_state; // toggle
}

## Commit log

2024-07-05 Make initial public release
    [base.stl, clip.stl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]
2024-07-05 Add clip plastic for Acrab release (version 15)
    [clip_base_15.f3d, clip_base_15.step]
2024-07-05 Add latest (unreleased) clip plastic design
    [clip_base_24.f3d, clip_base_24.step]
2024-07-05 Fix broken links in kicad library readme
2024-07-05 Add modified case plastic design for MTA1 programmer
    [base-mta1.stl, base-tk1.stl, clip-mta1.stl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]
2024-07-05 TK-1 and TP-1 PCBs (#52)
    * Add kicad library for flat programming clip
    * Add descriptions to part symbols
    * Add extended values, manufacturer/distributor info to components in mta1
    * Add new board entry for TK1
    * Add TP1 programmer design
    * Update MTA1-USB-V1 release files to match production
    * Change SPI flash memory type to XT25F08BDFIGT-S
    * Change touch sensor feedback cap to 1uF
    * Add manufacturer, manufacturer part number, distributor, distributor part number
    * Update component values for TK1 PCB
    * Use specific part # for C8
    * Change flash back to Winbond part, for easier sourcing
    * Change C1 to 1pF
    * Fixes for production programmer PCB
    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
    [mta1-usb-v1-programmer.csv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]
2024-07-05 Pull in programmer board firmware
2024-07-05 pico: change USB vendor to Tillitis
2024-07-05 Add Pico SDK to docker image, for building tp1 firmware
2024-07-05 New plastic clip and update BOM for TP1
    [clip_base_30.3mf, clip_base_30.stp, clip_base_spacer_30.stp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]
2024-09-05 Moved and filtered commits and files from tillitis/tillitis-key1
    The filtering removes all files and commits that are not related to the
    tp1 hardware. This is done using `git-filter-repo`. To replicate the
    results here, checkout commit `354aecb` in tillitis/tillitis-key1 and
    run `git-filter-repo --path hw/boards/tp1 --path
    hw/boards/mta1-usb-v1-programmer --path hw/boards/KiCad-RP Pico`.
    All commits have intact date, author, and code. Some unrelated files are
    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
2024-09-05 Move mta1-usb-v1-programmer to prototypes
    [base-mta1.stl, base-tk1.stl, clip-mta1.stl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]
2024-09-05 Move tp1 directly under hw/
    - Move libraries to `hw/lib/`
    - rename gerbers to gerber
    [clip_base_15.f3d, clip_base_15.step, clip_base_24.f3d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]
2024-09-05 Add common gitignore for kicad projects
2024-09-05 Added mta1-library and updated project links
    - Updated links to symbols, footprints, drawsheet, 3D models
    - Made the links use project defines instead of being absolute
    [tp1.kicad_pcb, tp1.kicad_sch]
2024-09-05 Fix bug in symbol, pin set to wrong electrical type.
    - Pico: Pin 38 GND set to `Power input` instead of `bidirectional`
2024-09-05 Fix all ERC errors.
    - Update symbols
    - Add PWR_FLAG
    [tp1.kicad_sch]
2024-09-05 Fix all DRC errors
    - Update Pico footprint with courtyard and component type
    - Updated 3D model for jig and component type
    [tp1.kicad_pcb]
2024-09-05 Add Kibot to build in CI
    - Makefile to ease local build
    - Kibot config
    - Filter silkscreen issues
    - Add output to gitignore
2024-09-05 Remove generated files from repository.
    - Keeping generated files makes it harder to keep a consistent version
    control. These files are to be included in the releases.
    - These files can be generated in CI or locally for any commit.
    [mta1-usb-v1-programmer-B_Cu.gbr, mta1-usb-v1-programmer-B_Mask.gbr, mta1-usb-v1-programmer-B_Paste.gbr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]
2024-09-05 Update links to library and 3D-models for the prototype mta1-usb-v1-programmer.
    [mta1-usb-v1-programmer.kicad_pcb, mta1-usb-v1-programmer.kicad_sch]
2024-09-20 Add picture of prototype mta1-usb-v1-programmer
2026-10-16 feat(fw): add vendor bulk transfer support
    Implement `tud_vendor_rx_cb()` to handle bulk OUT commands from the host.
    Add support for `COMMAND_SPI_XFER` and `COMMAND_PIN_VALUES`. Handle
    SPI read responses asynchronously via bulk IN in the main loop.
    - Increase `CFG_TUD_VENDOR_RX_BUFSIZE` and `CFG_TUD_VENDOR_TX_BUFSIZE` to 2048
    - Bump `PROTOCOL_VERSION` to 0x0201
2026-10-16 feat: add bulk transfer support for SPI clockout
    - Handle COMMAND_SPI_CLKOUT in the USB bulk vendor callback
    - Document bulk packet format and fix control transfer payload sizes in README
    - Fix grammar in data packet format descriptions
